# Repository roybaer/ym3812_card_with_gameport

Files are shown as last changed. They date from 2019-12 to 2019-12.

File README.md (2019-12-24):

# YM3812 card with gameport

This 8-bit ISA card is essentially a clone of Amstrad's Adlib clone with gameport.

The routing and silk screen are a bit tidier and the DA15 connector has been shifted to make it easier to adapt off-the-shelf slot brackets.

## Front view

This picture shows the front of the card.

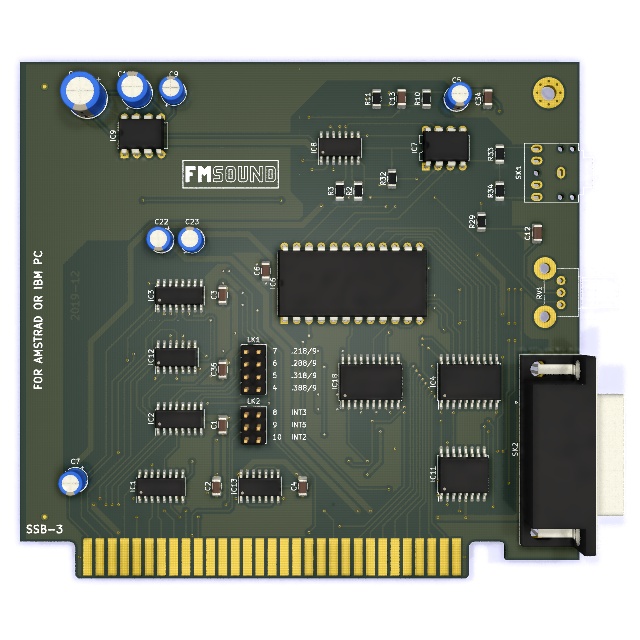
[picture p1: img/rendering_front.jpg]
Front view


## Vintage components

Besides readily available standard components, the card uses four vintage components:

- Yamaha YM3812 (OPL2 FM synthesizer)
- Yamaha Y3014B (matching DAC for OPL2)
- TDA7233 (amplifier)
- NE558 (quad timer IC)

## License

The following license applies to the files in this repository:

This work is licensed under the Creative Commons Attribution-ShareAlike 4.0 International License. To view a copy of this license, visit http://creativecommons.org/licenses/by-sa/4.0/ or send a letter to Creative Commons, PO Box 1866, Mountain View, CA 94042, USA.

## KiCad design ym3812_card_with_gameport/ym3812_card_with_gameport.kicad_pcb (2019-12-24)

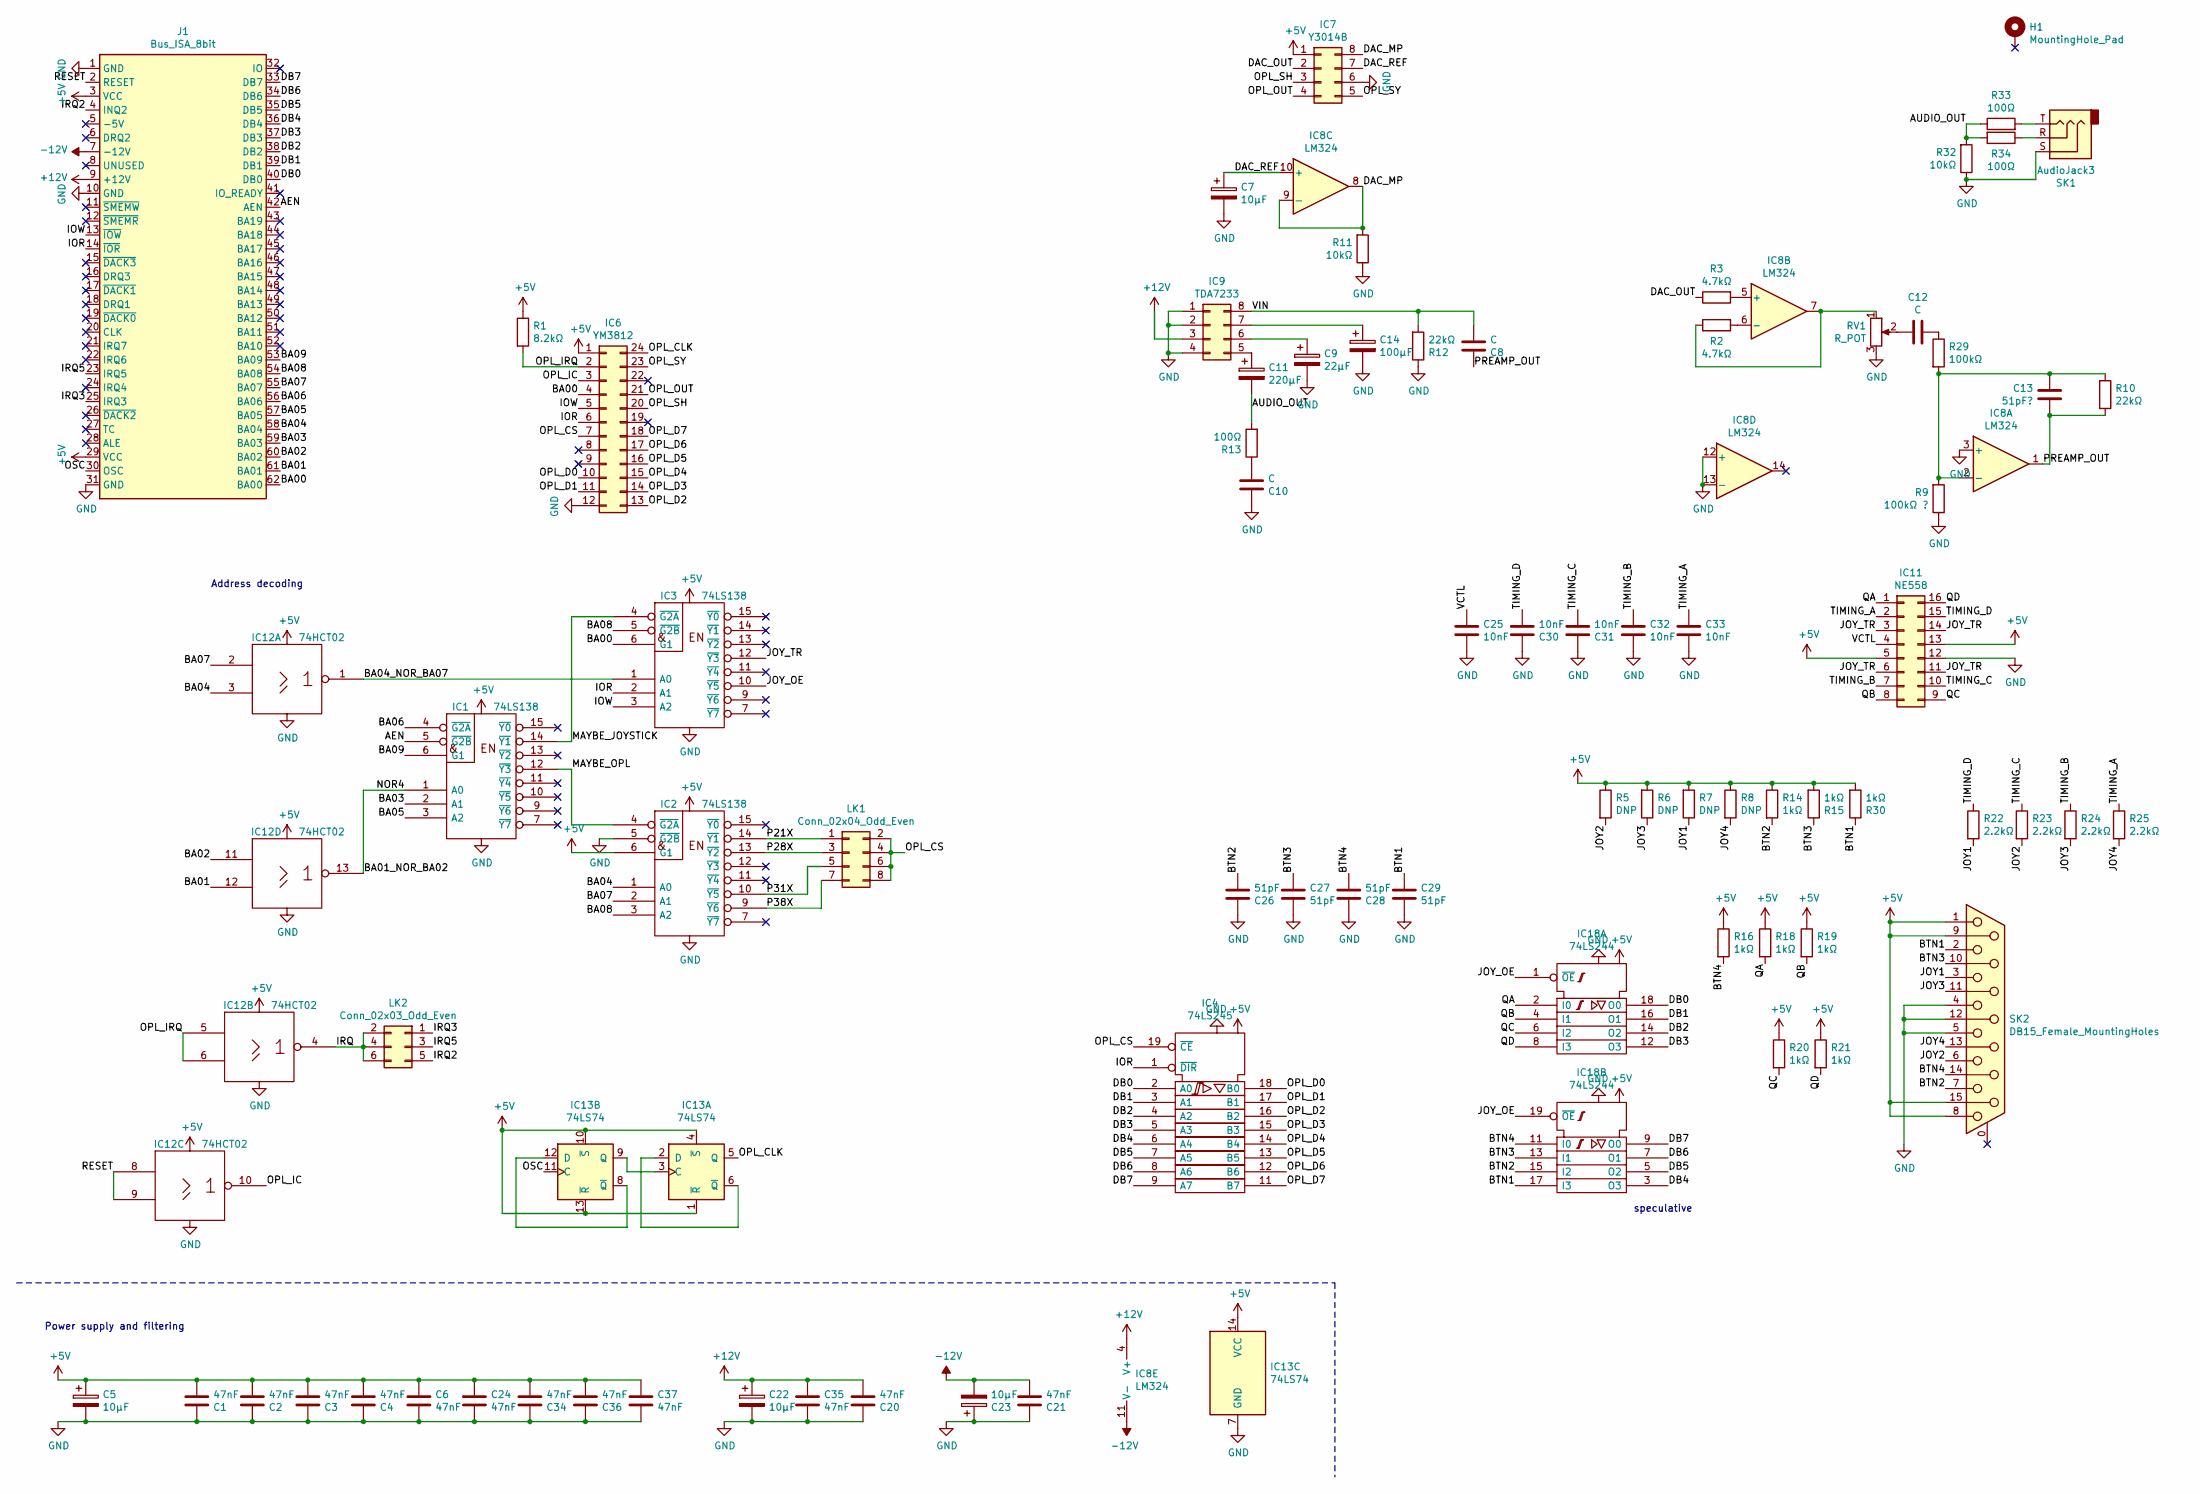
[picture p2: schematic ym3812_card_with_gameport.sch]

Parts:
C1, C2, C3, C4, C6, C20, C21, C24, C34, C35, C36, C37: 47nF; C_1206_3216Metric
C5, C7, C22, C23: 10µF; CP_Radial_D5.0mm_P2.50mm
C8, C10, C12: C; C_1206_3216Metric
C9: 22µF; CP_Radial_D5.0mm_P2.50mm
C11: 220µF; CP_Radial_D8.0mm_P5.00mm
C13: 51pF?; C_1206_3216Metric
C14: 100µF; CP_Radial_D6.3mm_P2.50mm
C25, C30, C31, C32, C33: 10nF; C_1206_3216Metric
C26, C27, C28, C29: 51pF; C_1206_3216Metric
H1: MountingHole_Pad; MountingHole_3.2mm_M3_Pad_Via
IC1, IC2, IC3: 74LS138; SOIC-16_3.9x9.9mm_P1.27mm
IC4: 74LS245; SOIC-20W_7.5x12.8mm_P1.27mm
IC6: YM3812; DIP-24_W15.24mm
IC7: Y3014B; DIP-8_W7.62mm
IC8: LM324; SOIC-14_3.9x8.7mm_P1.27mm
IC9: TDA7233; DIP-8_W7.62mm
IC11: NE558; SOIC-16W_7.5x10.3mm_P1.27mm
IC12: 74HCT02; SOIC-14_3.9x8.7mm_P1.27mm
IC13: 74LS74; SOIC-14_3.9x8.7mm_P1.27mm
IC18: 74LS244; SOIC-20W_7.5x12.8mm_P1.27mm
J1: Bus_ISA_8bit; BUS_AT
LK1: Conn_02x04_Odd_Even; PinHeader_2x04_P2.54mm_Vertical
LK2: Conn_02x03_Odd_Even; PinHeader_2x03_P2.54mm_Vertical
R1: 8.2kΩ; R_1206_3216Metric
R2, R3: 4.7kΩ; R_1206_3216Metric
R5, R6, R7, R8: DNP; R_1206_3216Metric
R9: 100kΩ ?; R_1206_3216Metric
R10, R12: 22kΩ; R_1206_3216Metric
R11, R32: 10kΩ; R_1206_3216Metric
R13, R33, R34: 100Ω; R_1206_3216Metric
R14, R15, R16, R18, R19, R20, R21, R30: 1kΩ; R_1206_3216Metric
R22, R23, R24, R25: 2.2kΩ; R_1206_3216Metric
R29: 100kΩ; R_1206_3216Metric
RV1: R_POT; Potentiometer_Alps_RK09K_Single_Horizontal
SK1: AudioJack3; Jack_3.5mm_CUI_SJ1-3525N_Horizontal
SK2: DB15_Female_MountingHoles; DSUB-15_Female_Horizontal_P2.77x2.84mm_EdgePinOffset7.70mm_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

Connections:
+5V: C1.2, C2.2, C3.2, C4.2, C5.1, C6.1, C24.1, C34.2, C36.2, C37.1, IC1.16 (VCC), IC2.6 (G1), IC2.16 (VCC), IC3.16 (VCC), IC4.20 (VCC), IC6.1, IC7.1, IC11.5, IC11.13, IC12.14 (VCC), IC13.1 (~R), IC13.4 (~S), IC13.10 (~S), IC13.13 (~R), IC13.14 (VCC), IC18.20 (VCC), J1.3 (VCC), J1.29 (VCC), R1.1, R5.1, R6.2, R7.2, R8.1, R14.1, R15.2, R16.1, R18.1, R19.1, R20.1, R21.1, R30.2, SK2.1, SK2.8, SK2.9, SK2.15
+12V: C20.2, C22.1, C35.1, IC8.4 (V+), IC9.3, J1.9 (+12V)
-12V: C21.2, C23.2, IC8.11 (V-), J1.7 (-12V)
/AEN: IC1.5 (~G2B), J1.42 (AEN)
/AUDIO_OUT: C11.2, R13.2, R32.2, R33.1, R34.2
/BA00: IC3.6 (G1), IC6.4, J1.62 (BA00)
/BA01: IC12.12, J1.61 (BA01)
/BA01_NOR_BA02: IC1.1 (A0), IC12.13
/BA02: IC12.11, J1.60 (BA02)
/BA03: IC1.2 (A1), J1.59 (BA03)
/BA04: IC2.1 (A0), IC12.3, J1.58 (BA04)
/BA04_NOR_BA07: IC3.1 (A0), IC12.1
/BA05: IC1.3 (A2), J1.57 (BA05)
/BA06: IC1.4 (~G2A), J1.56 (BA06)
/BA07: IC2.2 (A1), IC12.2, J1.55 (BA07)
/BA08: IC2.3 (A2), IC3.5 (~G2B), J1.54 (BA08)
/BA09: IC1.6 (G1), J1.53 (BA09)
/BTN1: C29.1, IC18.17 (I3), R30.1, SK2.2
/BTN2: C26.2, IC18.15 (I2), R14.2, SK2.7
/BTN3: C27.1, IC18.13 (I1), R15.1, SK2.10
/BTN4: C28.2, IC18.11 (I0), R16.2, SK2.14
/DAC_MP: IC7.8, IC8.8, IC8.9 (-), R11.2
/DAC_OUT: IC7.2, R3.1
/DAC_REF: C7.1, IC7.7, IC8.10 (+)
/DB0: IC4.2 (A0), IC18.18 (O0), J1.40 (DB0)
/DB1: IC4.3 (A1), IC18.16 (O1), J1.39 (DB1)
/DB2: IC4.4 (A2), IC18.14 (O2), J1.38 (DB2)
/DB3: IC4.5 (A3), IC18.12 (O3), J1.37 (DB3)
/DB4: IC4.6 (A4), IC18.3 (O3), J1.36 (DB4)
/DB5: IC4.7 (A5), IC18.5 (O2), J1.35 (DB5)
/DB6: IC4.8 (A6), IC18.7 (O1), J1.34 (DB6)
/DB7: IC4.9 (A7), IC18.9 (O0), J1.33 (DB7)
/IOR: IC3.2 (A1), IC4.1 (~DIR), IC6.6, J1.14 (~IOR)
/IOW: IC3.3 (A2), IC6.5, J1.13 (~IOW)
/IRQ: IC12.4, LK2.2, LK2.4, LK2.6
/IRQ2: J1.4 (INQ2), LK2.5
/IRQ3: J1.25 (IRQ3), LK2.1
/IRQ5: J1.23 (IRQ5), LK2.3
/JOY1: R7.1, R22.2, SK2.3
/JOY2: R5.2, R23.2, SK2.6
/JOY3: R6.1, R24.2, SK2.11 (P111)
/JOY4: R8.2, R25.2, SK2.13
/JOY_OE: IC3.10 (~Y5), IC18.1 (~OE), IC18.19 (~OE)
/JOY_TR: IC3.12 (~Y3), IC11.3, IC11.6, IC11.11, IC11.14
/MAYBE_JOYSTICK: IC1.14 (~Y1), IC3.4 (~G2A)
/MAYBE_OPL: IC1.12 (~Y3), IC2.4 (~G2A)
/OPL_CLK: IC6.24, IC13.5 (Q)
/OPL_CS: IC4.19 (~CE), IC6.7, LK1.2, LK1.4, LK1.6, LK1.8
/OPL_D0: IC4.18 (B0), IC6.10
/OPL_D1: IC4.17 (B1), IC6.11
/OPL_D2: IC4.16 (B2), IC6.13
/OPL_D3: IC4.15 (B3), IC6.14
/OPL_D4: IC4.14 (B4), IC6.15
/OPL_D5: IC4.13 (B5), IC6.16
/OPL_D6: IC4.12 (B6), IC6.17
/OPL_D7: IC4.11 (B7), IC6.18
/OPL_IC: IC6.3, IC12.10
/OPL_IRQ: IC6.2, IC12.5, IC12.6, R1.2
/OPL_OUT: IC6.21, IC7.4
/OPL_SH: IC6.20, IC7.3
/OPL_SY: IC6.23, IC7.5
/OSC: IC13.11 (C), J1.30 (OSC)
/P21X: IC2.14 (~Y1), LK1.1
/P28X: IC2.13 (~Y2), LK1.3
/P31X: IC2.10 (~Y5), LK1.5
/P38X: IC2.9 (~Y6), LK1.7
/PREAMP_OUT: C8.1, C13.1, IC8.1, R10.1
/QA: IC11.1, IC18.2 (I0), R18.2
/QB: IC11.8, IC18.4 (I1), R19.2
/QC: IC11.9, IC18.6 (I2), R20.2
/QD: IC11.16, IC18.8 (I3), R21.2
/RESET: IC12.8, IC12.9, J1.2 (RESET)
/TIMING_A: C33.1, IC11.2, R25.1
/TIMING_B: C32.1, IC11.7, R24.1
/TIMING_C: C31.2, IC11.10, R23.1
/TIMING_D: C30.2, IC11.15, R22.1
/VCTL: C25.1, IC11.4
/VIN: C8.2, IC9.8, R12.2
GND: C1.1, C2.1, C3.1, C4.1, C5.2, C6.2, C7.2, C9.2, C10.1, C14.2, C20.1, C21.1, C22.2, C23.1, C24.2, C25.2, C26.1, C27.2, C28.1, C29.2, C30.1, C31.1, C32.2, C33.2, C34.1, C35.2, C36.1, C37.2, IC1.8 (GND), IC2.5 (~G2B), IC2.8 (GND), IC3.8 (GND), IC4.10 (GND), IC6.12, IC7.6, IC8.3 (+), IC8.12 (+), IC8.13 (-), IC9.1, IC9.2, IC9.4, IC11.12, IC12.7 (GND), IC13.7 (GND), IC18.10 (GND), J1.1 (GND), J1.10 (GND), J1.31 (GND), R9.1, R11.1, R12.1, R32.1, RV1.3, SK1.S, SK2.4, SK2.5, SK2.12
unnamed: C9.1, IC9.6
unnamed: C10.2, R13.1
unnamed: C11.1, IC9.5
unnamed: C12.1, RV1.2
unnamed: C12.2, R29.1
unnamed: C13.2, IC8.2 (-), R9.2, R10.2, R29.2
unnamed: C14.1, IC9.7
unnamed: IC8.5 (+), R3.2
unnamed: IC8.6 (-), R2.2
unnamed: IC8.7, R2.1, RV1.1
unnamed: IC13.2 (D), IC13.6 (~Q)
unnamed: IC13.3 (C), IC13.9 (Q)
unnamed: IC13.8 (~Q), IC13.12 (D)
unnamed: R33.2, SK1.T
unnamed: R34.1, SK1.R

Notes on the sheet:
speculative
Power supply and filtering
Address decoding

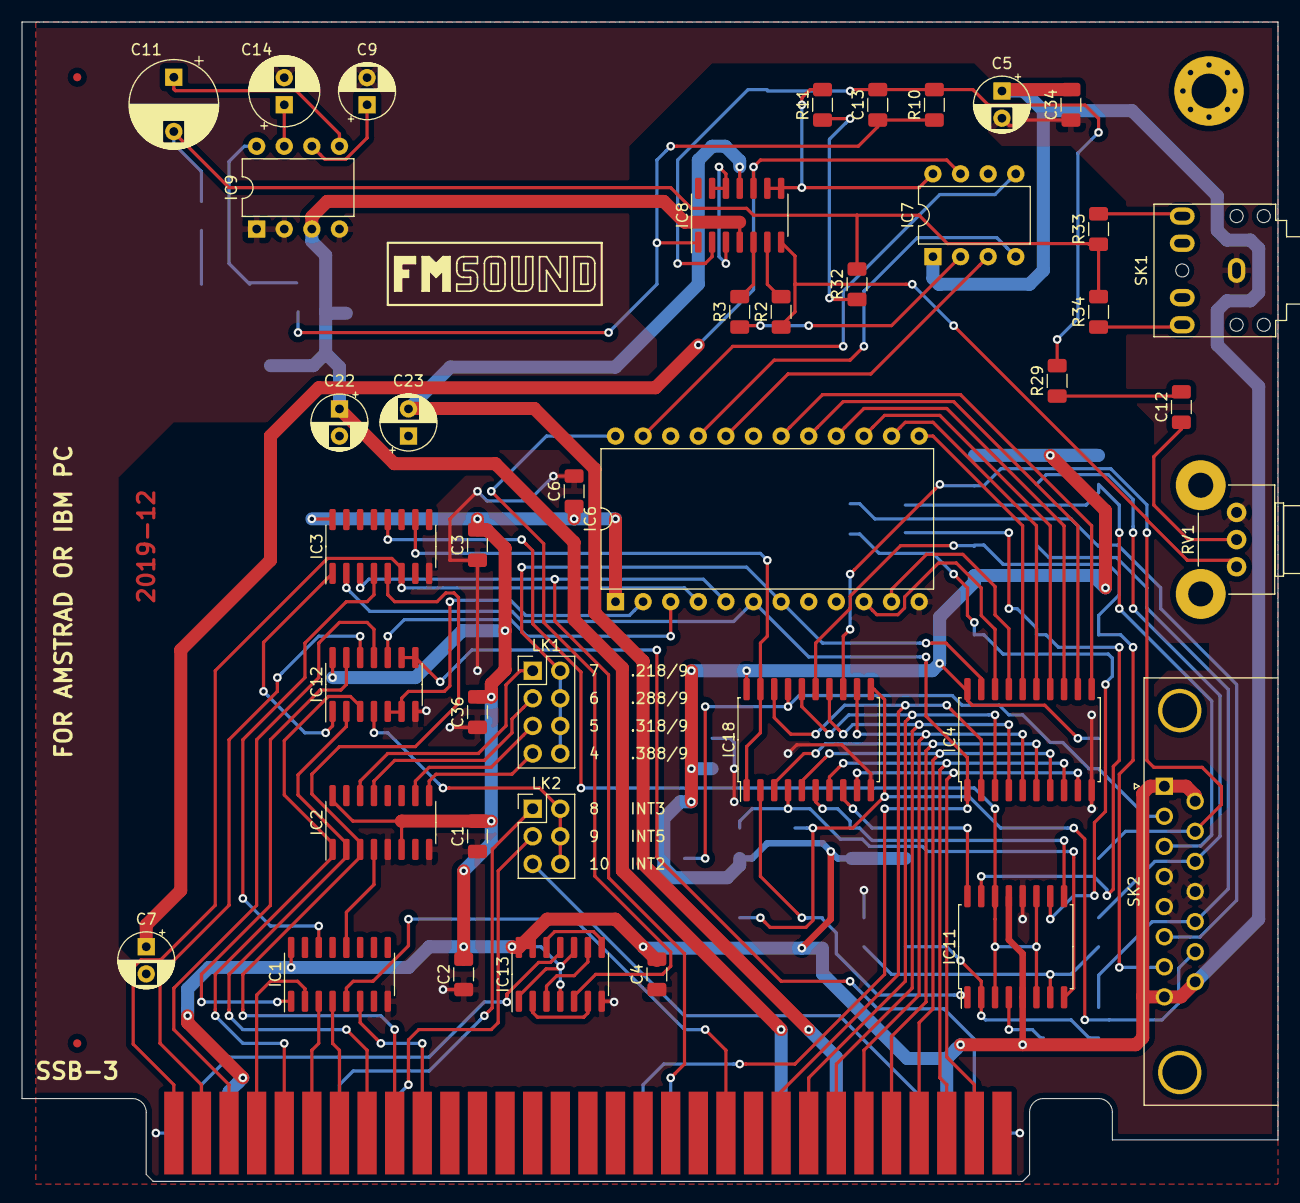
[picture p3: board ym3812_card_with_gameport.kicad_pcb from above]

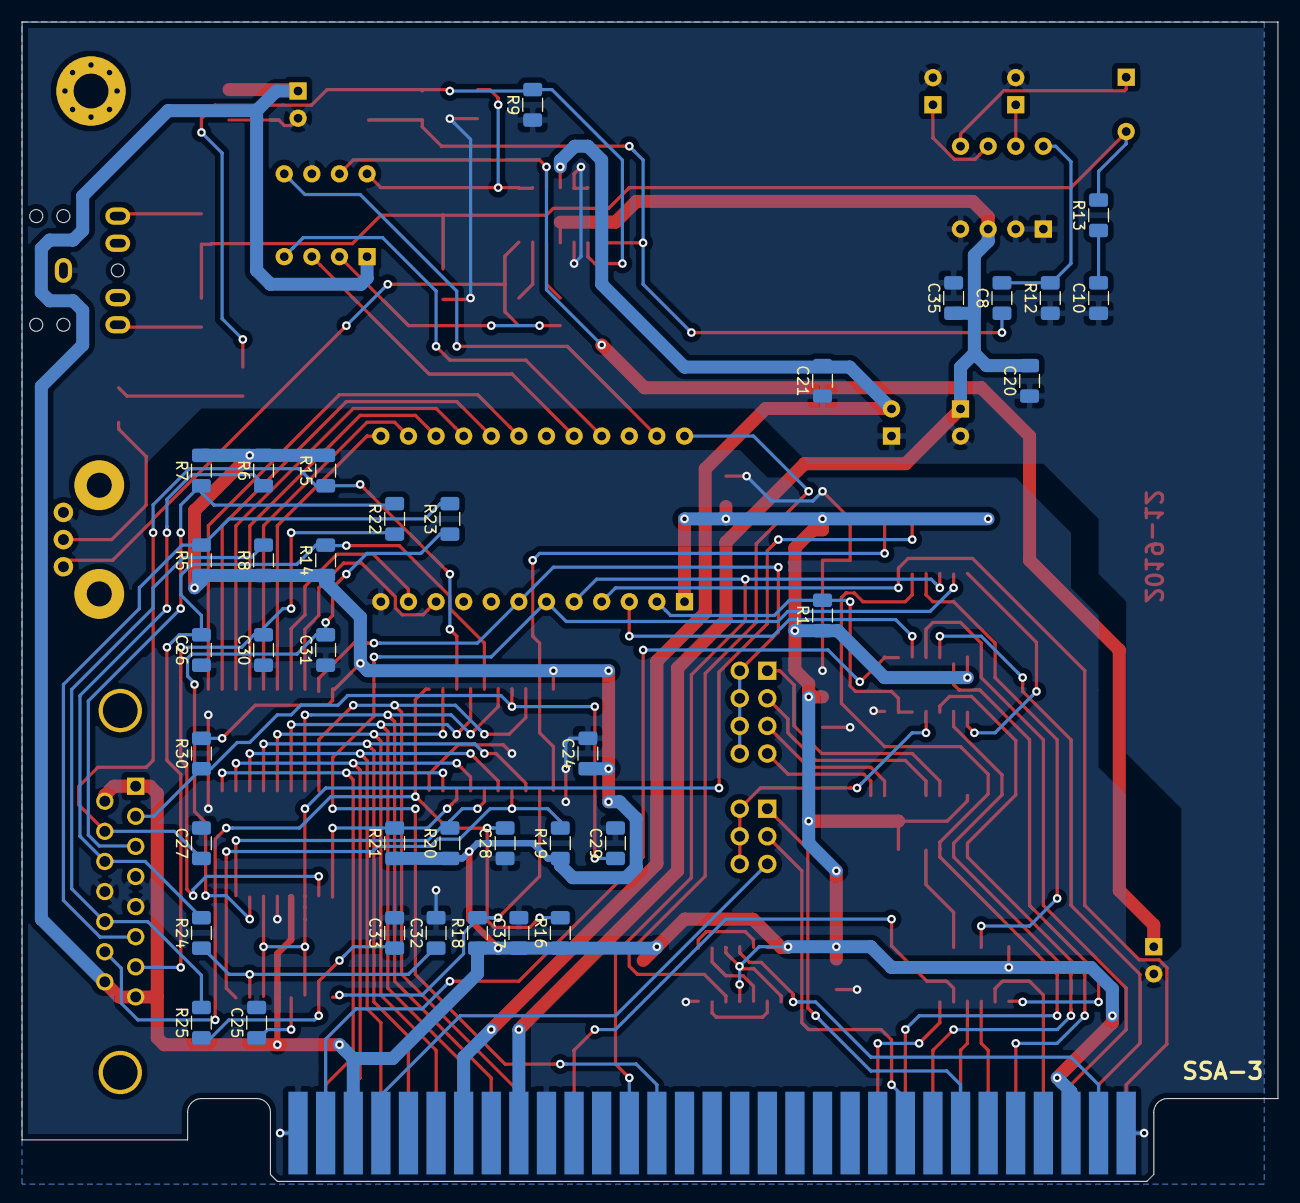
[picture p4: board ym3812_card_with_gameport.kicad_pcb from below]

Board: 2 copper layers, 115.6 x 106.7 mm, 79 parts (36 on the bottom side), 94 nets.

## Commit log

2019-10-29 some corrections, GND and VCC
    [ym3812_card_with_gameport.kicad_pcb, ym3812_card_with_gameport.sch]
2019-11-17 mostly complete schematic
    [ym3812_card_with_gameport.kicad_pcb, ym3812_card_with_gameport.sch]
2019-11-28 more accurate component positions
    [ym3812_card_with_gameport.kicad_pcb]
2019-12-06 corrections and some new traces
    [ym3812_card_with_gameport.kicad_pcb, ym3812_card_with_gameport.sch]
2019-12-23 minor corrections, routing complete
    [ym3812_card_with_gameport.kicad_pcb, ym3812_card_with_gameport.sch]
2019-12-23 layout beautification
    [ym3812_card_with_gameport.kicad_pcb]
2019-12-23 adapt to Keystone bracket 9200-3
    [ym3812_card_with_gameport.kicad_pcb]
2019-12-24 adjust edge connector
    [ym3812_card_with_gameport.kicad_pcb]
2019-12-24 mark R5, R6, R7 and R8 as DNP
    [ym3812_card_with_gameport.kicad_pcb, ym3812_card_with_gameport.sch]
